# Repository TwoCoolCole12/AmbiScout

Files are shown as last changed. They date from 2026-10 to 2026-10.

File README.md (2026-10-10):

# AmbiScout
A portable environment sensor to sense ambient temperature, humidity, light, movement speed, and more!

Inspired by features on the Starbie, but extended for functionality and development time. 

Living in a place where the climate constantly fluctuates, it can be handy to glance at a small device that's 
not a phone to see what's happening in the air around oneself.



Here's some of the planned features:

- [x] Temperature Sensor
- [x] Humidity Sensor
- [x] Battery Powered or Rechargeability
- [x] OLED Display
- [x] Navigation Buttons
- [x] Power/Charging Indicator
- [x] Ambient Light Level Monitor
- [x] Audio Sensor

Checks does not mean it's programmed, just accounted for and wired.

With enough work, it might be reasonable to add in these features too, but they are lower priority:

- [ ] Wi-Fi Connection
- [ ] Bluetooth Compatiblitiy
- [ ] Access to Weather Forcasts
- [ ] Push Notifications when Major Changes Occue
- [ ] Charging & Battery Info
- [ ] CO2 Sensor
- [x] Barometric Pressure Sensor
- [ ] Built in Clock
- [ ] Movement Sensor



**Hardware Specifications** WIP

* Espressif ESP32-S3-MINI-1-N8 - Chosen due to high pin number, Wi-Fi and Bluetooth connectivity, compatibility with Arduino, and low cost for the given performance
  * Pin Layout Reference: https://documentation.espressif.com/esp32-s3-mini-1_mini-1u_datasheet_en.html
* Light Dependent Resistor A1050 14 - Selected due to native support in KiCad and high sensitivity
  * Pin Reference: https://www.caretxdigital.com/cat6-ethernet-cable-amazon/
* I2C SHT31-DIS Temperature & Humidity Sensor - Chosen due to accuracy and multifunctionality
  * Pin Reference: https://www.alldatasheet.com/datasheet-pdf/view/1522466/SENSIRION/SHT31-DIS.html
* SPH0655LM4H-1-8 Sound Sensor - Chosen for compactness and price point
  * Pin Reference: https://mm.digikey.com/Volume0/opasdata/d220001/medias/docus/6634/SPH0655LM4H-1-8.pdf

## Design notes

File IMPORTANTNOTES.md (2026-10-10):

Some parts of the overall design will not be implemented/purchased yet due to cost restrictions.
This includes:
* The Battery [DigiKey_Link](https://www.digikey.com/en/products/detail/mikroelektronika/MIKROE-4473/13679425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)
* Motion/Movement Sensor
* CO2 Sensor

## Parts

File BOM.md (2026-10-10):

# AmbiScout – bill of materials

<!-- Generated by Half Life from project cmuzxkajc008201k9c68hd4dr. Edits here are overwritten on the next sync. -->
<!-- Generated: 2026-10-10T14:32:10.378Z -->

> [!NOTE]
> This parts list is mirrored from [Half Life](https://halflife.hackclub.com). Editing it here will not change the platform's copy, and the next sync overwrites this file.

| Week | Tier | Parts funding |
| --- | --- | --- |
| Week 1 | Tier 2 | $65.00 |

| Part | What it's for | Qty | Unit | Total | Vendor |
| --- | --- | --- | --- | --- | --- |
| [ESP32-S3-MINI-1-N8](https://www.digikey.com/en/products/detail/espressif-systems/ESP32-S3-MINI-1-N8/15295890) | Microcontroller as the Main Brain, Wi-Fi and Bluetooth support | 1 | $5.43 | $5.43 | [DigiKey](https://www.digikey.com/en/products/detail/espressif-systems/ESP32-S3-MINI-1-N8/15295890) |
| [SHT31-DIS-B2.5KS](https://www.digikey.com/en/products/detail/sensirion-ag/SHT31-DIS-B2-5KS/5872252) | Temperature & Humidity Sensor | 1 | $5.00 | $5.00 | [DigiKey](https://www.digikey.com/en/products/detail/sensirion-ag/SHT31-DIS-B2-5KS/5872252) |
| [WEA012864DBPP3N00003](https://www.digikey.com/en/products/detail/winstar-display/WEA012864DBPP3N00003/20533257) | OLED Display Screen | 1 | $7.82 | $7.82 | [DigiKey](https://www.digikey.com/en/products/detail/winstar-display/WEA012864DBPP3N00003/20533257) |
| [TPS63802DLAR](https://www.digikey.com/en/products/detail/texas-instruments/TPS63802DLAR/10715525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) | Voltage Regulation when Powered by USB-C | 1 | $3.40 | $3.40 | [DigiKey](https://www.digikey.com/en/products/detail/texas-instruments/TPS63802DLAR/10715525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) |
| [BQ24074RGTR](https://www.digikey.com/en/products/detail/texas-instruments/BQ24074RGTR/2047269) | Battery Charging | 1 | $2.43 | $2.43 | [DigiKey](https://www.digikey.com/en/products/detail/texas-instruments/BQ24074RGTR/2047269) |
| [SPH0655LM4H-1-8](https://www.digikey.com/en/products/detail/syntiant/SPH0655LM4H-1-8/11506922) | Audio Level Sensor | 1 | $1.69 | $1.69 | [DigiKey](https://www.digikey.com/en/products/detail/syntiant/SPH0655LM4H-1-8/11506922) |
| [CF18JT5K10](https://www.digikey.com/en/products/detail/stackpole-electronics-inc/CF18JT5K10/1741724) | 5.1kΩ Resistor | 2 | $0.10 | $0.20 | [DigiKey](https://www.digikey.com/en/products/detail/stackpole-electronics-inc/CF18JT5K10/1741724) |
| [CF14JT3K00](https://www.digikey.com/en/products/detail/stackpole-electronics-inc/CF14JT3K00/1741418) | 3kΩ Resistor | 1 | $0.10 | $0.10 | [DigiKey](https://www.digikey.com/en/products/detail/stackpole-electronics-inc/CF14JT3K00/1741418) |
| [CF18JT1K80](https://www.digikey.com/en/products/detail/stackpole-electronics-inc/CF18JT1K80/1741557) | 1.8kΩ Resistor | 1 | $0.10 | $0.10 | [DigiKey](https://www.digikey.com/en/products/detail/stackpole-electronics-inc/CF18JT1K80/1741557) |
| [CF14JT91K0](https://www.digikey.com/en/products/detail/stackpole-electronics-inc/CF14JT91K0/1741530) | 91kΩ Resistor | 1 | $0.10 | $0.10 | [DigiKey](https://www.digikey.com/en/products/detail/stackpole-electronics-inc/CF14JT91K0/1741530) |
| [RNF14FTD511K](https://www.digikey.com/en/products/detail/stackpole-electronics-inc/RNF14FTD511K/1682328) | 511kΩ Resistor | 1 | $0.10 | $0.10 | [DigiKey](https://www.digikey.com/en/products/detail/stackpole-electronics-inc/RNF14FTD511K/1682328) |
| [CL21B106KOQNNNE](https://www.digikey.com/en/products/detail/samsung-electro-mechanics/CL21B106KOQNNNE/3888530) | 10μF Capacitor | 4 | $0.27 | $1.08 | [DigiKey](https://www.digikey.com/en/products/detail/samsung-electro-mechanics/CL21B106KOQNNNE/3888530) |
| [CL31A226KPHNNNE](https://www.digikey.com/en/products/detail/samsung-electro-mechanics/CL31A226KPHNNNE/3889373) | 22μF Capacitor | 1 | $0.47 | $0.47 | [DigiKey](https://www.digikey.com/en/products/detail/samsung-electro-mechanics/CL31A226KPHNNNE/3889373) |
| [CL21B104KBCNNNC](https://www.digikey.com/en/products/detail/samsung-electro-mechanics/CL21B104KBCNNNC/3886661) | 100nF Capacitor | 3 | $0.10 | $0.30 | [DigiKey](https://www.digikey.com/en/products/detail/samsung-electro-mechanics/CL21B104KBCNNNC/3886661) |
| [1825910-6](https://www.digikey.com/en/products/detail/te-connectivity-alcoswitch-switches/1825910-6/1632536) | Navigation Buttons | 4 | $0.13 | $0.52 | [DigiKey](https://www.digikey.com/en/products/detail/te-connectivity-alcoswitch-switches/1825910-6/1632536) |
| [SM02B-SRSS-TB](https://www.digikey.com/en/products/detail/jst-sales-america-inc/SM02B-SRSS-TB/926708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) | Battery Connector | 1 | $0.38 | $0.38 | [DigiKey](https://www.digikey.com/en/products/detail/jst-sales-america-inc/SM02B-SRSS-TB/926708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) |
| [BMP384](https://www.digikey.com/en/products/detail/bosch-sensortec/BMP384/13681277) | Barometric Pressure Sensor | 1 | $3.81 | $3.81 | [DigiKey](https://www.digikey.com/en/products/detail/bosch-sensortec/BMP384/13681277) |
| [PDV-P8103](https://www.digikey.com/en/products/detail/advanced-photonix/PDV-P8103/480610) | Photoresistor | 1 | $0.72 | $0.72 | [DigiKey](https://www.digikey.com/en/products/detail/advanced-photonix/PDV-P8103/480610) |
| [MAMK2520HR47M](https://www.digikey.com/en/products/detail/taiyo-yuden/MAMK2520HR47M/5361238) | Inductor for the Regulator | 1 | $0.19 | $0.19 | [DigiKey](https://www.digikey.com/en/products/detail/taiyo-yuden/MAMK2520HR47M/5361238) |
| [USB4105-GF-A](https://www.digikey.com/en/products/detail/gct/USB4105-GF-A/11198441) | USB-C Receptacle for Data Transfer & Power | 1 | $0.80 | $0.80 | [DigiKey](https://www.digikey.com/en/products/detail/gct/USB4105-GF-A/11198441) |
| **Parts subtotal** | — | — | — | **$34.64** | — |
| **Tax & shipping** | — | — | — | **$12.13** | — |
| **Total** | — | — | — | **$46.77** | — |

$18.23 left of the tier's funding.

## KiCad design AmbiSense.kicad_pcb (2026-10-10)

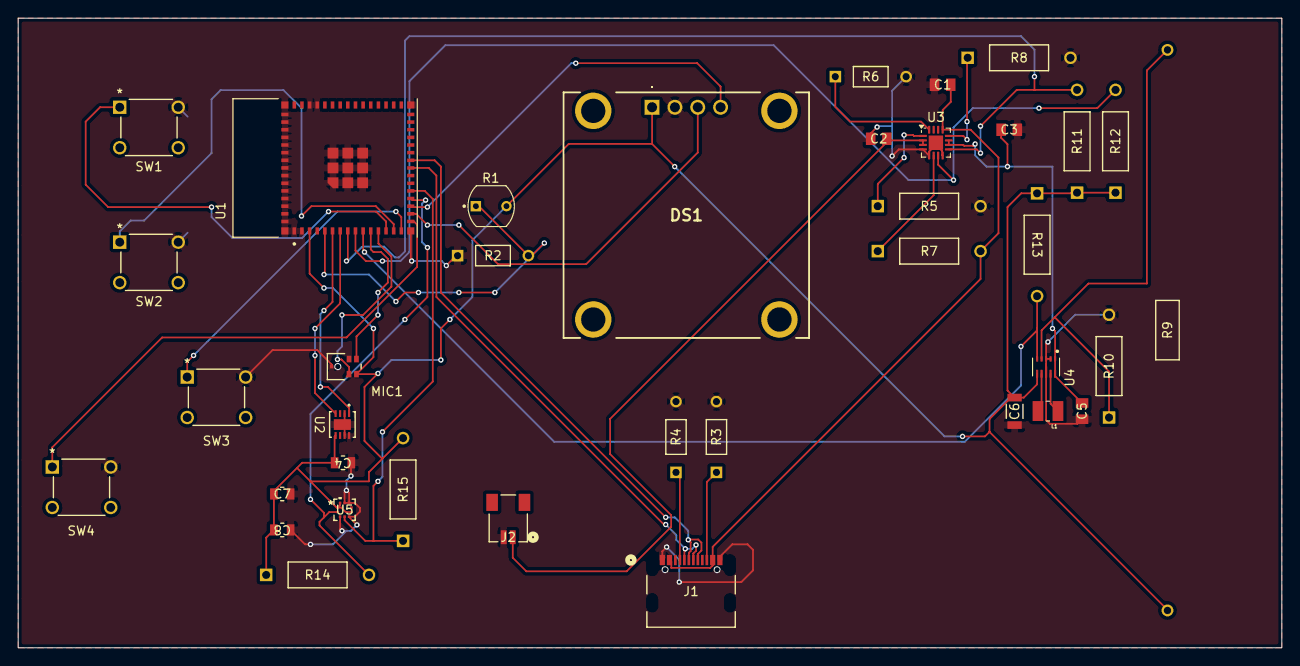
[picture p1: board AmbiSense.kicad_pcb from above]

Board: 2 copper layers, 140.5 x 70.0 mm, 37 parts (0 on the bottom side), 32 nets.

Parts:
C1, C2, C3, C5: 10µF; Cap10UF
C4, C7, C8: 100nF; Cap100nF
C6: 22µF; Cap22UF
DS1: WEA012864DWPP3N00003
J1: USB4105-GF-A; USB4105_GCT
J2: SM02B-SRSS-TB LFSN; CONN_SM02B-SRSS-TB_JST
L1: 0.47 µH; INDC2520X120N
MIC1: SPH0655LM4H-1; SPH0655LM4H-1_KNO
R1: PDV-P8103; PHODET_PDV-P8103
R2: 100K; Res100kO
R3, R4: 5.1K; Res5.1kO
R5, R7, R11, R12, R13: 10k; Res10kO
R6: 1.8k; Res1.8kO
R8: 3k; Res3kO
R9: 511k; Res511kO
R10: 91k; Res91kO
R14, R15: 4.7kΩ; Res4.7kO
SW1, SW2, SW3, SW4: SW_Push; SW4_1825910-B_TEC
U1: ESP32-S3-MINI-1-N8; XCVR_ESP32-S3-MINI-1-N8
U2: SHT31-DIS; U_SHT3_SEN
U3: BQ24074RGT; VQFN-16-1EP_3x3mm_P0.5mm_EP1.6x1.6mm
U4: TPS63802DLAR; VREG_TPS63802DLAR
U5: BMP384; LGA10_2.0X2.0X0.95_BOS

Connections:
/3V3_POWER: C4.2, C6.2, C7.1, C8.2, DS1.1 (VCC), MIC1.5 (VDD), R1.2, R9.1, R11.1, R12.1, R13.1, R14.1, R15.2, U1.3 (3V3), U2.5 (VDD), U4.6 (VOUT), U5.1 (VDDIO), U5.6 (CSB), U5.10 (VDD)
/AUDIO_CLOCK: MIC1.4 (CLOCK), U1.12 (IO8)
/AUDIO_DATA: MIC1.1 (DATA), U1.11 (IO7)
/BAT_POS: C2.2, J2.1, U3.2 (BAT), U3.3 (BAT)
/BCK_SW: SW4.1, U1.16 (IO12)
/CHG STATUS: R11.2, U1.8 (IO4), U3.9 (~CHG)
/DOWN_SW: SW2.1, U1.14 (IO10)
/LDR_I/O: R1.1, R2.2, U1.5 (IO1)
/OLED_SCL: DS1.3 (SCL), U1.17 (IO13)
/OLED_SDA: DS1.4 (SDA), U1.18 (IO14)
/PGOOD STATUS: R12.2, U1.9 (IO5), U3.7 (~PGOOD)
/PRESS_SCL: R14.2, U1.19 (IO15), U5.2 (SCK)
/PRESS_SDA: R15.1, U1.20 (IO16), U5.4 (SDI)
/REG PGOOD: R13.2, U1.10 (IO6), U4.5 (PG)
/SEL_SW: SW3.1, U1.15 (IO11)
/SYS_PWR: C3.1, C5.2, U3.10 (OUT), U3.11 (OUT), U4.1 (EN), U4.10 (VIN)
/T&H SCL: U1.7 (IO3), U2.4 (SCL)
/T&H SDA: U1.6 (IO2), U2.1 (SDA)
/UP_SW: SW1.1, U1.13 (IO9)
/USB 5V: C1.2, J1.A4-B9 (VBUS), J1.B4-A9 (VBUS), R7.2, U3.13 (IN)
/USB D+: J1.A6 (DP1), J1.B6 (DP2), U1.24 (IO20)
/USB D-: J1.A7 (DN1), J1.B7 (DN2), U1.23 (IO19)
GND: C1.1, C2.1, C3.2, C4.1, C5.1, C6.1, C7.2, C8.1, DS1.2 (GND), J1.A1-B12 (GND), J1.B1-A12 (GND), J2.2, MIC1.3 (GROUND), R2.1, R3.2, R4.2, R5.2, R6.2, R8.2, R10.2, SW1.2, SW2.2, SW3.2, SW4.2, U1.1 (GND), U1.2 (GND), U1.42 (GND), U1.43 (GND), U1.46 (GND), U1.47 (GND), U1.48 (GND), U1.49 (GND), U1.50 (GND), U1.51 (GND), U1.52 (GND), U1.53 (GND), U1.54 (GND), U1.55 (GND), U1.56 (GND), U1.57 (GND), U1.58 (GND), U1.59 (GND), U1.60 (GND), U1.61 (GND), U1.61_1 (GND), U1.61_2 (GND), U1.61_3 (GND), U1.61_4 (GND), U1.61_5 (GND), U1.61_6 (GND), U1.61_7 (GND), U1.61_8 (GND), U1.62 (GND), U1.63 (GND), U1.64 (GND), U1.65 (GND), U2.2 (ADDR), U2.7 (R), U2.8 (VSS), U2.9 (VSS), U3.4 (~CE), U3.5 (EN2), U3.8 (VSS), U3.17 (VSS), U4.2 (MODE), U4.3 (AGND), U4.8 (GND), U5.3 (VSS), U5.5 (SDO), U5.8 (VSS), U5.9 (VSS)
unnamed: J1.A5 (CC1), R4.1
unnamed: J1.B5 (CC2), R3.1
unnamed: R7.1, U3.6 (EN1)
unnamed: R8.1, U3.12 (ILIM)
unnamed: R6.1, U3.16 (ISET)
unnamed: R5.1, U3.1 (TS)
unnamed: R9.2, R10.1, U4.4 (FB)
unnamed: L1.1, U4.9 (L1)
unnamed: L1.2, U4.7 (L2)

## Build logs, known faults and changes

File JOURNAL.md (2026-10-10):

# AmbiScout – devlog

<!-- Generated by Half Life from project cmuzxkajc008201k9c68hd4dr. Edits here are overwritten on the next sync. -->
<!-- Generated: 2026-10-10T19:41:43.622Z -->

> [!NOTE]
> This devlog is mirrored from [Half Life](https://halflife.hackclub.com). Editing it here will not change the platform's copy, and the next sync overwrites this file.

> A portable environment sensor to sense ambient temperature, humidity, light, movement speed, and more! Inspired by features on the Starbie, but extended for functionality and development time. Living in a place where the climate constantly fluctuates, it can be handy to glance at a small device that's not a phone to see what's happening around me.

| Week | Tier | Hours logged | Entries |
| --- | --- | --- | --- |
| Week 1 | Tier 2 | 18.5h | 5 |

## Contents

1. [2026-10-09 – Well, today was a crazy one.](#2026-10-09-well-today-was-a-crazy-one)
2. [2026-10-10 – Started off today with a little bit of a different focus, which was planning things out a little more. I spent a little bit drawing up a rough sketch of what I wanted the board to look like although i](#2026-10-10-started-off-today-with-a-little-bit-of-a-differen)
3. [2026-10-10 – Same day, different session. This time, I went back to the schematic and footprints. I went through and found components for the pressure sensor, and I also redid the audio sensor. I had to change the](#2026-10-10-same-day-different-session-this-time-i-went-back-)
4. [2026-10-10 – So, progress was made and it wasn't. I actually laid out the PCB without any errors when importing the schematic. After a little organization, I think I'm ready to start the actual traces. But first,](#2026-10-10-so-progress-was-made-and-it-wasnt-i-actually-laid)
5. [2026-10-10 – I did it! Two hours of troubleshooting and finally no more errors. I had to edit the footprint on the audio sensor because the hole was slightly too big and the actual GND pad was absolutely miniscule](#2026-10-10-i-did-it-two-hours-of-troubleshooting-and-finally)

## Design

### 2026-10-09 – Well, today was a crazy one.

**7h**

Well, today was a crazy one.

I decided to restart week 1 to pursue my own project for two major reasons:
1. The Starbie Project wouldn't have given me enough hours to complete the week
2. By doing my own project, I can learn more about the design process and I get gain a better understanding.

So, I created a new repository and KiCad project for the new project: AmbiSense. It's a portable environment sensor that has capabilities to sense external light levels, sound levels, humidity, and temperature.

And so, with a fresh start came a new README.md and blank schematic





The next steps I had to take were... interesting. I had to select and find the parts I wanted to use in order to make this thing real, and found a couple places to look, those being DigiKey, Octopart, and SnapMagic.



The first step of course was choosing the brain of this operation, and I settled on the ESP32-S2. It has lots of pins, Wi-Fi and Bluetooth capabilities, and more. It was perfect. After some searching, I also found a pin layout and datasheet for it that would help me know where to connect things. Data sheets I also used for almost every other new component to tell me what to connect to where and whether it needed something like a resistor or capacitor.







Once I chose the microcontroller, I found it in the KiCad library and placed it.



I started with something simple next: The light sensor. For this, I chose to use a light dependent resistor and hooked it up in accordance to some diagrams I found, and I used net labels to help with organizing.





I moved on to a dual-purpose sensor for temperature and humidity. In hindsight, it would have been smart to just use the same one as the Starbie, but too late. Plus, why not go big or go home right? Anyways, same process as the LDR.









The next part took the better part of this session. I wanted to incorporate a rechargeability feature, which was much more complicated than I thought. I needed to wire in a USB-C receiver, which already had tons of pins to connect, some of which I didn't even see on my microcontroller at first.





It was around now that I decided to look into my microcontroller a little more and I discovered that the ESP32-S2 wasn't in stock almost anywhere. So, I pivoted. I decided on a little upgrade and went for the ESP32-S3-MINI-1. It has even more pins, and clearer documentation, plus it was in stock. Being from the same family I didn't have to change all that much, although I did have to import my own symbol for it that I found on SnapMagic.



After that was sorted out, I started on the power system again. Over the course of many hours, I searched for datasheets and wired in receivers, sockets, converters, and chargers. Although it was stupid complicated, there was lots of documentation from Texas Instruments who produced the most complicated parts, so in the end I was able to have it wired correctly (I think) and even have power and charging indications routed to the ESP32 for later usage.







To wrap up the session, I decided to go a little bit easier. I set up the OLED and buttons using the Starbie guide and used some footprints from the starter pack as I expect I'll just use the same ones. I also wired up a sound sensor. It has 3 I/O connections, but with the low pin count, it was actually pretty easier to wire in. I expect that the coding portion will be much more difficult and tedious.









And with that, a long long long session was complete. Now I know that datasheets are one's best friend when it comes to new components, and I am just a bit better at wiring I think. Next steps are to make it into a PCB and potentially add another sensor or connectivity device if I find the time and use for one.



### 2026-10-10 – Started off today with a little bit of a different focus, which was planning things out a little more. I spent a little bit drawing up a rough sketch of what I wanted the board to look like although i

**2.5h**

Started off today with a little bit of a different focus, which was planning things out a little more. I spent a little bit drawing up a rough sketch of what I wanted the board to look like although it's not exactly to scale.







Once that was done, I set up some spaces in KiCad to add a pressure sensor, a movement sensor, and a CO2 sensor.



However, after looking for some actual parts to use, I realized that some of them were listed as really expensive on SnapMagic. So, I put KiCad on hold and decided to get a financial scope for what I already had, and to make a BOM. So, I opened up all my saved pages for the components, but because so many of them were in different sites or just a database, I realized I needed one site that ships components and has their prices. And so, DigiKey was selected. I went through and found all my parts and added them to a cart for reference. Except that my audio sensor I had selected was actually no longer produced, so I had to pivot to a different model.











Eventually, I finished the current BOM on the Half Life site. I also included resistors and capacitors and stuff as separate entities because they all have different links even if they are all on the same site. Plus, it helps me keep track of costs. Luckily, I have some resistors that my project needs already, so I don't have to factor those into the budget. I still need to add some components as I add capacitors and resistors for additional sensors, but now I see my headroom. However, some components like the CO2 sensor, accelerometer, and rechargeable battery are too expensive for my budget, so I'm leaving them out for now as they are not strictly necessary. I've added some notes in GitHub that detail that and will also detail other important notes. And so, I have my current budget set and am ready to add the last couple schematics.





### 2026-10-10 – Same day, different session. This time, I went back to the schematic and footprints. I went through and found components for the pressure sensor, and I also redid the audio sensor. I had to change the

**3.25h**

Same day, different session. This time, I went back to the schematic and footprints. I went through and found components for the pressure sensor, and I also redid the audio sensor. I had to change the audio sensor component because as I was doing the bill of materials, I found that the previous one was no longer made. But I went and set up the schematics;



I wired up the audio sensor;



I then moved onto the pressure sensor. This component was new, so I needed to find a datasheet to tell me how to correctly connect it, and I did. I found a diagram specifically for I2C, which is what I am using.





And after a bit, I got it wired up too, which after some schematic tweaks in other places for specific components rather than a general one, that completed the schematic.





Now it's time to do the footprints.



 I decided to download all the footprints from online sources to guarantee that the PCB would be correct, and I even did that for the specific capacitors and resistors I'm using. That was an extremely tedious process, but in the end, I got it done and got the kicad_mod files imported. And that brings us to where I am now, ready to start the PCB design with all the footprints correctly assigned and ready.





### 2026-10-10 – So, progress was made and it wasn't. I actually laid out the PCB without any errors when importing the schematic. After a little organization, I think I'm ready to start the actual traces. But first,

**3.75h**

So, progress was made and it wasn't. I actually laid out the PCB without any errors when importing the schematic. After a little organization, I think I'm ready to start the actual traces. But first, the ground plane really helped clean up unnecessary traces and made things at least a little cleaner.







While doing the traces, I found out that you can route through to the back (or front) of the board. That made routing certain traces way easier.



And now all the traces are complete, with the ground plane redone to account for all the traces.



However, now I have a bunch of errors when running the DRC. I was able to resolve most of them fairly quickly, but there are some stubborn ones primarily around my sound sensor. The GND pad doesn't connect to any traces or ground planes, and doesn't want to, and that makes things a whole lot more annoying.



But that's the last step for this project other than getting a starting code going on GitHub. This project I actually found more fun than the Starbie because I was able to figure out so much by myself. It's a nice feeling. Welp, back to troubleshooting.

### 2026-10-10 – I did it! Two hours of troubleshooting and finally no more errors. I had to edit the footprint on the audio sensor because the hole was slightly too big and the actual GND pad was absolutely miniscule

**2h**

I did it! Two hours of troubleshooting and finally no more errors. I had to edit the footprint on the audio sensor because the hole was slightly too big and the actual GND pad was absolutely miniscule. But that's all fixed up and everything is connected up, meaning this PCB is complete! (Minus some silkscreen warnings but eh, I don't really care too much cause I have the design in front of me.
